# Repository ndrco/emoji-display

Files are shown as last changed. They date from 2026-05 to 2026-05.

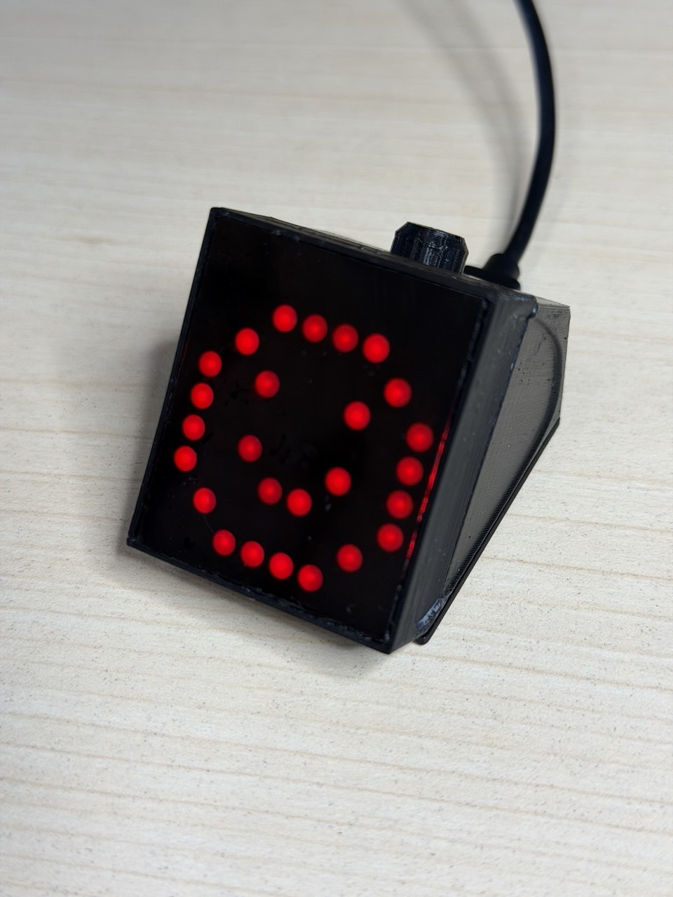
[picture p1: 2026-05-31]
Arduino/Case 3d model/photo_2026-05-31_19-20-57.jpg

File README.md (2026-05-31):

# emoji-display

`emoji-display` is a local bridge between applications and a small Arduino LED
emoji panel. It owns the serial port, normalizes incoming emoji to the limited
set supported by the 8x8 matrix, and exposes both HTTP and CLI interfaces.

The bundled firmware lives in
[`Arduino/max7219_emoji_panel`](Arduino/max7219_emoji_panel). Flash the Arduino
first, then come back here to install the daemon.

Files for the printable enclosure live in
[`Arduino/Case 3d model`](Arduino/Case%203d%20model).

## What You Get

- A local HTTP daemon for showing emoji on the panel.
- A `displayctl` CLI for testing and debugging.
- Automatic emoji normalization such as `😺 -> CAT`, `🚀 -> CAR`,
  `🌸 -> FLOWER`, `☔ -> RAIN`.
- Serial port auto-detection when the Arduino changes from `/dev/ttyACM0` to
  `/dev/ttyACM1`.
- `systemd` service templates for both system-wide and per-user installs.

## Quick Start

This is the shortest path from a freshly flashed Arduino to a working local
service on Linux.

1. Flash the firmware from
   [`Arduino/max7219_emoji_panel`](Arduino/max7219_emoji_panel).
2. Disconnect the Arduino IDE Serial Monitor after flashing.
3. Find the stable serial path:

```bash
ls -l /dev/serial/by-id/
```

You want the Arduino path, for example:

```text
/dev/serial/by-id/usb-Arduino_LLC_Arduino_Micro-if00
```

4. Clone the repository and install it:

```bash
git clone https://github.com/ndrco/emoji-display.git
cd emoji-display
python3 -m venv .venv
. .venv/bin/activate
pip install -e ".[dev]"
```

5. Start the daemon manually:

```bash
emoji-displayd --driver serial --serial-port /dev/serial/by-id/usb-Arduino_LLC_Arduino_Micro-if00
```

6. In another terminal, check that it is alive:

```bash
curl http://127.0.0.1:18791/v1/status
displayctl --url http://127.0.0.1:18791 status
```

When the driver opens the port it logs the resolved device, for example:

```text
opening serial display port /dev/serial/by-id/usb-Arduino_LLC_Arduino_Micro-if00 (configured)
```

If that works, continue to one of the service setups below.

## Requirements

- Linux, macOS, or Windows.
- Python 3.10+.
- A flashed Arduino-compatible board connected over USB.
- `pyserial` is installed automatically with the package.

Linux users should prefer `/dev/serial/by-id/...` over `/dev/ttyACM0` or
`/dev/ttyUSB0`, because the `by-id` path stays stable across reconnects.

## Run Manually

Explicit port:

```bash
emoji-displayd --driver serial --serial-port /dev/serial/by-id/usb-Arduino_LLC_Arduino_Micro-if00
```

Auto-detect:

```bash
emoji-displayd --driver serial
```

Auto-detect works well when one Arduino-like serial device is clearly
identifiable. When several USB serial devices are connected, the daemon tries
to prefer real Arduino metadata and then probes candidates for the panel boot
banner.

Windows PowerShell example:

```powershell
.\.venv\Scripts\emoji-displayd --driver serial --serial-port COM3
```

## Service Setup

There are two supported service styles:

- `systemd --user`: easiest when you install into your home directory and do
  not want `sudo`.
- system-wide `systemd`: best when the service should survive logout and live in
  `/opt/emoji-display`.

## User Service

This is the easiest GitHub-friendly Linux install.

1. Install the repo in your preferred location, for example
   `/home/<user>/Applications/emoji-display`.
2. Create an environment file:

```bash
mkdir -p ~/.config/emoji-display
cp packaging/systemd/emoji-display.env.example ~/.config/emoji-display/emoji-display.env
```

3. Edit `~/.config/emoji-display/emoji-display.env`.

Recommended:

```bash
EMOJI_DISPLAY_PORT=/dev/serial/by-id/usb-Arduino_LLC_Arduino_Micro-if00
```

Or leave `EMOJI_DISPLAY_PORT` unset to use auto-detection.

4. Create `~/.config/systemd/user/emoji-display.service`:

```ini
[Unit]
Description=Emoji Display Arduino bridge
Documentation=https://github.com/ndrco/emoji-display
After=default.target

[Service]
Type=simple
WorkingDirectory=/home/USER/Applications/emoji-display
EnvironmentFile=-/home/USER/.config/emoji-display/emoji-display.env
ExecStart=/home/USER/Applications/emoji-display/.venv/bin/emoji-displayd --driver serial
Restart=on-failure
RestartSec=3
NoNewPrivileges=true
PrivateTmp=true

[Install]
WantedBy=default.target
```

Replace `USER` with your real username.

5. Enable and start it:

```bash
systemctl --user daemon-reload
systemctl --user enable --now emoji-display.service
```

6. Verify:

```bash
systemctl --user status emoji-display.service
journalctl --user -u emoji-display.service -f
curl http://127.0.0.1:18791/v1/status
```

## System-Wide Service

Use this when you want a conventional machine-wide service.

```bash
sudo useradd --system --home-dir /opt/emoji-display \
  --shell /usr/sbin/nologin --groups dialout emoji-display
sudo mkdir -p /etc/emoji-display
sudo git clone https://github.com/ndrco/emoji-display.git /opt/emoji-display
sudo python3 -m venv /opt/emoji-display/.venv
sudo /opt/emoji-display/.venv/bin/pip install -e /opt/emoji-display
sudo cp packaging/systemd/emoji-display.env.example /etc/emoji-display/emoji-display.env
sudo nano /etc/emoji-display/emoji-display.env
sudo cp packaging/systemd/emoji-display.service /etc/systemd/system/emoji-display.service
sudo systemctl daemon-reload
sudo systemctl enable --now emoji-display
```

Then verify:

```bash
sudo systemctl status emoji-display
sudo journalctl -u emoji-display -f
curl http://127.0.0.1:18791/v1/status
```

Use a stable port in `/etc/emoji-display/emoji-display.env` when possible:

```bash
EMOJI_DISPLAY_PORT=/dev/serial/by-id/usb-Arduino_LLC_Arduino_Micro-if00
```

If you leave the port unset, watch the journal for the resolved port name.

## Verify The Install

Useful checks after any install:

```bash
curl http://127.0.0.1:18791/v1/status
displayctl --url http://127.0.0.1:18791 status
displayctl --url http://127.0.0.1:18791 supported
displayctl --url http://127.0.0.1:18791 show "😺"
displayctl --url http://127.0.0.1:18791 clear --reason test
```

Expected signs of success:

- `/v1/status` returns `"connected": true`.
- The reported `"port"` is the Arduino serial device.
- Logs contain `opening serial display port ...`.
- The matrix reacts to `displayctl show`.

## Troubleshooting

`The daemon says "multiple serial ports found"`:
Use `/dev/serial/by-id/...` explicitly, or disconnect the other USB serial
devices while testing.

`Nothing happens on the display`:
Make sure the Arduino IDE Serial Monitor is closed. Only one process can own the
serial port at a time.

`Permission denied on /dev/ttyACM0 or /dev/ttyUSB0`:
Your user probably needs the serial group, usually `dialout`. Some
distributions use `uucp` or `lock` instead.

`The Arduino changes from /dev/ttyACM0 to /dev/ttyACM1`:
Use `/dev/serial/by-id/...` in your env file instead of the moving `/dev/tty*`
name.

`The service started but the first HTTP request feels slow`:
The serial driver opens the Arduino lazily on first use and may wait for the
board reset timeout before the first response.

`Auto-detect still picks the wrong device`:
Pin `EMOJI_DISPLAY_PORT` to the exact `/dev/serial/by-id/...` path.

## Supported Display Names

The Arduino panel currently contains these display names:

```text
HAPPY LAUGH WINK SURPRISE SAD CRY ANGRY LOVE KISS COOL SLEEP NEUTRAL
CONFUSED THINK TONGUE DEAD WOW HEART YES NO OK ALERT MUSIC ROBOT GHOST
CAT DOG FOOD STAR CAR FLOWER RAIN DEFAULT
```

Emoji without an exact hardware drawing are classified by domain when possible:

- transport -> `CAR`
- plants -> `FLOWER`
- weather -> `RAIN`
- food and drinks -> `FOOD`
- music and instruments -> `MUSIC`
- sparkles, fireworks, stars -> `STAR`
- truly unknown -> `DEFAULT`

To add a new hardware icon, add frames to
[`Arduino/max7219_emoji_panel/emojis.h`](Arduino/max7219_emoji_panel/emojis.h)
and then add normalization rules in
[`src/emoji_display/emoji.py`](src/emoji_display/emoji.py).

## CLI

```bash
displayctl status
displayctl supported
displayctl normalize "😺"
displayctl show "😺"
displayctl clear --reason interrupt
```

Use top-level options before the command when the daemon is not running on
`http://127.0.0.1:18791`:

```bash
displayctl --url http://127.0.0.1:18791 status
```

If the daemon uses a bearer token, pass `--token`.

## HTTP API

`GET /v1/status`

```json
{
  "ok": true,
  "connected": true,
  "driver": "serial",
  "current": "😺",
  "display_name": "CAT",
  "display_symbol": "🐱",
  "queue_size": 0,
  "last_error": null
}
```

`GET /v1/supported`

`POST /v1/show`

```json
{
  "symbol": "😺",
  "name": "smiling_cat_face",
  "hold_ms": 7000,
  "mode": "replace",
  "source": "listener",
  "id": "run-123:segment-4:0"
}
```

If `hold_ms` is omitted, the server uses its default `7000` ms.

When a new symbol arrives while another one is still fresh, the daemon keeps
the current symbol for at most `1600` ms total, then replaces it with the latest
incoming symbol. The Arduino firmware has its own standalone default `1600` ms,
used only when the board receives `EMO <name>` without an explicit duration.

`POST /v1/sequence` is accepted for compatibility, but it never queues display
items. The daemon selects the last item in the request and ignores the rest.

`POST /v1/clear`

```json
{
  "source": "listener",
  "reason": "interrupt"
}
```

If `--token` is set, clients must send `Authorization: Bearer <token>`.

## Firmware And Hardware Notes

The wiring guide, component list, and firmware details live in
[`Arduino/max7219_emoji_panel/README.md`](Arduino/max7219_emoji_panel/README.md).
That document covers:

- required Arduino and MAX7219 hardware
- LDR and potentiometer wiring
- Arduino IDE setup
- the serial protocol
- manual hardware testing
- tuning brightness and animation timing

## Enclosure Files

Printable case assets live in
[`Arduino/Case 3d model`](Arduino/Case%203d%20model):

- `Top.stl`
- `Bottom.stl`
- `Display.stl`
- `Glass.stl`
- `Knob.stl`

The folder also includes:

- `Smileficator v18.png` as a render/preview
- `photo_2026-05-31_19-20-57.jpg` as a real build photo
- `video_2026-05-31_19-21-24.mp4` as a short demo clip

## Development

```bash
.venv/bin/python -m pytest -q
```

The Arduino helper
[`Arduino/max7219_emoji_panel/test_all_emojis.py`](Arduino/max7219_emoji_panel/test_all_emojis.py)
is a manual hardware test, not a pytest test:

```bash
python Arduino/max7219_emoji_panel/test_all_emojis.py /dev/ttyACM0
```

## Listener Config Example

```json
{
  "speaker": {
    "emoji_display": {
      "enabled": true,
      "url": "http://127.0.0.1:18791",
      "timeout_s": 0.25,
      "mode": "replace",
      "source": "listener",
      "send": "last",
      "clear_on_interrupt": true
    }
  }
}
```

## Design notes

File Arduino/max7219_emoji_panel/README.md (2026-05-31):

# MAX7219 8x8 Emoji Panel

Firmware for an Arduino-compatible board connected to one MAX7219 8x8 LED
matrix. The Python daemon sends normalized emoji names over Serial, and this
sketch renders the matching built-in animation.

After flashing the board, return to the repository root
[`README.md`](../../README.md) for daemon installation, service setup, and
verification steps.

If you want a printable enclosure for the hardware, see
[`../Case 3d model`](../Case%203d%20model).

## Components

- Arduino Pro Micro / Leonardo-compatible ATmega32U4 board, 5 V version.
- MAX7219 8x8 LED matrix module.
- LDR photoresistor, for example GL5528.
- 10 kOhm resistor for the LDR divider.
- 10 kOhm potentiometer for user brightness limit.
- Breadboard/jumper wires and a USB data cable.

Other Arduino boards can work too. If you use Uno, Nano, ESP32, or another
pinout, update `PIN_DIN`, `PIN_CLK`, and `PIN_CS` in `config.h`.

## Enclosure

3D-printable enclosure files are stored in
[`../Case 3d model`](../Case%203d%20model):

- `Top.stl`
- `Bottom.stl`
- `Display.stl`
- `Glass.stl`
- `Knob.stl`

That folder also contains one render image, one assembled-device photo, and one
short demo video for reference during printing and assembly.

## Wiring

The default pinout is for the current Pro Micro build:

A wiring snapshot is also available as
[`Schematic.png`](Schematic.png).

| Module | Arduino |
| --- | --- |
| MAX7219 VCC | 5V |
| MAX7219 GND | GND |
| MAX7219 DIN | D15 |
| MAX7219 CLK | D16 |
| MAX7219 CS | D10 |

LDR brightness sensor:

```text
5V --- LDR --- A0 --- 10 kOhm --- GND
```

Potentiometer:

```text
5V  --- outer pin
A1  --- middle pin
GND --- other outer pin
```

The LDR changes automatic brightness. The potentiometer limits the maximum
brightness so the display can be dimmed for a dark room.

## Arduino IDE Setup

1. Install the `LedControl` library from Library Manager.
2. Select a board matching your controller. For many Pro Micro clones, use
   `SparkFun Pro Micro` if SparkFun AVR boards are installed, or `Arduino
   Leonardo` for a compatible ATmega32U4 profile.
3. Open `max7219_emoji_panel.ino`.
4. Check pins and brightness calibration in `config.h`.
5. Upload the sketch.
6. Open Serial Monitor at `115200` baud with line ending `Newline`.

After power-up, the panel plays a short welcome splash once before it starts
accepting normal display commands. You can tune or disable this in `config.h`
with `STARTUP_SPLASH_ENABLED`, `STARTUP_SPLASH_FRAME_MS`, and
`STARTUP_SPLASH_HOLD_MS`.

## Serial Protocol

Commands are ASCII lines ending with `\n`:

```text
EMO <name> [ms] [fps]
IMG <b0> <b1> <b2> <b3> <b4> <b5> <b6> <b7> [ms]
LIST
CLEAR
DEBUG 1
DEBUG 0
HELP
```

Examples:

```text
EMO HAPPY 2000
EMO HEART 1600 15
EMO CAT 1600
CLEAR
LIST
IMG 0x3C 0x42 0xA5 0x81 0xA5 0x99 0x42 0x3C 1600
```

Responses used by the Python daemon:

```text
OK EMO CAT 1600
OK CLEAR
ERR: unknown EMO name. Try LIST.
```

`EMO` starts a non-blocking display state. While an animation is active, the
main loop still reads Serial, so a new `EMO` replaces the current one and
`CLEAR` clears the matrix immediately.

## Built-In Names

```text
HAPPY LAUGH WINK SURPRISE SAD CRY ANGRY LOVE KISS COOL SLEEP NEUTRAL
CONFUSED THINK TONGUE DEAD WOW HEART YES NO OK ALERT MUSIC ROBOT GHOST
CAT DOG FOOD STAR CAR FLOWER RAIN DEFAULT
```

Run `LIST` to get the same names with frame counts and FPS values.

## Manual Hardware Test

Close the Arduino IDE Serial Monitor before running the Python test helper.

```bash
python -m pip install pyserial
python Arduino/max7219_emoji_panel/test_all_emojis.py /dev/ttyACM0
```

On Windows:

```powershell
py -m pip install pyserial
py Arduino\max7219_emoji_panel\test_all_emojis.py COM3
```

The helper sends every name returned by `LIST`.

## Adding An Emoji

1. Add a PROGMEM name:

```cpp
const char NAME_MYEMO[] PROGMEM = "MYEMO";
```

2. Add frames. One frame is exactly 8 bytes, one byte per row:

```cpp
const uint8_t EMO_MYEMO[] PROGMEM = {
  // frame 0
  0b00111100, 0b01000010, 0b10100101, 0b10000001,
  0b10100101, 0b10011001, 0b01000010, 0b00111100,

  // frame 1
  0b00111100, 0b01000010, 0b10000001, 0b10000001,
  0b10100101, 0b10011001, 0b01000010, 0b00111100
};
```

3. Register it in `ANIMS`:

```cpp
{ NAME_MYEMO, EMO_MYEMO, 2, 7 },
```

The fields are `{ name, frame_array, frame_count, fps }`.
`frame_count` must be `1..MAX_ANIM_FRAMES`. `fps=0` uses
`DEFAULT_ANIM_FPS`.

4. Add Python normalization rules in
`src/emoji_display/emoji.py`, otherwise the daemon will not route user emoji to
the new display name.

## Tuning

Main settings are in `config.h`:

```cpp
const int LDR_DARK_ADC = 90;
const int LDR_BRIGHT_ADC = 760;
const uint8_t BRIGHTNESS_CURVE_PROFILE = 0;
const uint8_t MAX_ANIM_FRAMES = 4;
const uint8_t DEFAULT_ANIM_FPS = 8;
const uint8_t MIN_ANIM_FPS = 1;
const uint8_t MAX_ANIM_FPS = 30;
const uint16_t DEFAULT_SHOW_MS = 1600;
const int LDR_HYSTERESIS_ADC = 20;
```

If the LDR works backward because your divider is reversed, swap the LDR and
resistor positions or adjust `LDR_DARK_ADC` / `LDR_BRIGHT_ADC`.
If brightness still chatters near one light level, increase
`LDR_HYSTERESIS_ADC` a little, for example from `20` to `24` or `28`.

If the display becomes dim too quickly while room light falls, change
`BRIGHTNESS_CURVE_PROFILE`:

1. `0` = soft, keeps mid/low light levels brighter for longer.
2. `1` = balanced.
3. `2` = steep, darkens quickly.

If the LDR is mounted behind tinted glass or smoked acrylic, the ADC range
usually shifts downward a lot. In that case:

1. Send `DEBUG 1` in Serial Monitor.
2. Note `LDR raw=` in the darkest realistic condition.
3. Note `LDR raw=` in the brightest realistic condition.
4. Set `LDR_DARK_ADC` slightly below the dark reading.
5. Set `LDR_BRIGHT_ADC` slightly below or near the bright reading.

Example: if you see `raw=110` in the dark and `raw=720` in bright room light,
good starting values are `LDR_DARK_ADC = 90` and `LDR_BRIGHT_ADC = 760`.

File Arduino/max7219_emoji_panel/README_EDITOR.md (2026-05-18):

# emoji_editor.py

Графический редактор 8×8 анимаций для `emojis.h`.

## Запуск

```bash
cd max7219_emoji_panel
python3 emoji_editor.py
```

Если в системе нет Tkinter:

```bash
sudo apt install python3-tk
```

Можно явно указать файл и актуальную цифру Flash из Arduino IDE:

```bash
python3 emoji_editor.py --file ./emojis.h --flash-used 10466
```

## Что умеет

- открывать и сохранять `emojis.h`;
- редактировать 1–4 кадра для каждого эмодзи;
- задавать индивидуальный FPS;
- показывать Unicode emoji reference;
- подставлять имя по Unicode/CLDR-названию;
- приблизительно оценивать Flash;
- сохранять строки/столбцы во временном виртуальном буфере при сдвиге кадра;
- сбрасывать изменения текущего кадра кнопкой `Отменить`;
- сохранять текущий эмодзи кнопкой `Сохранить` с очисткой виртуального буфера;
- проигрывать анимацию текущего эмодзи кнопкой `Play`.

Оценка памяти приблизительная: редактор считает размер данных эмодзи во Flash (`имя + кадры + строка таблицы AnimDef`) и добавляет его к базовой оценке скетча из последней компиляции.

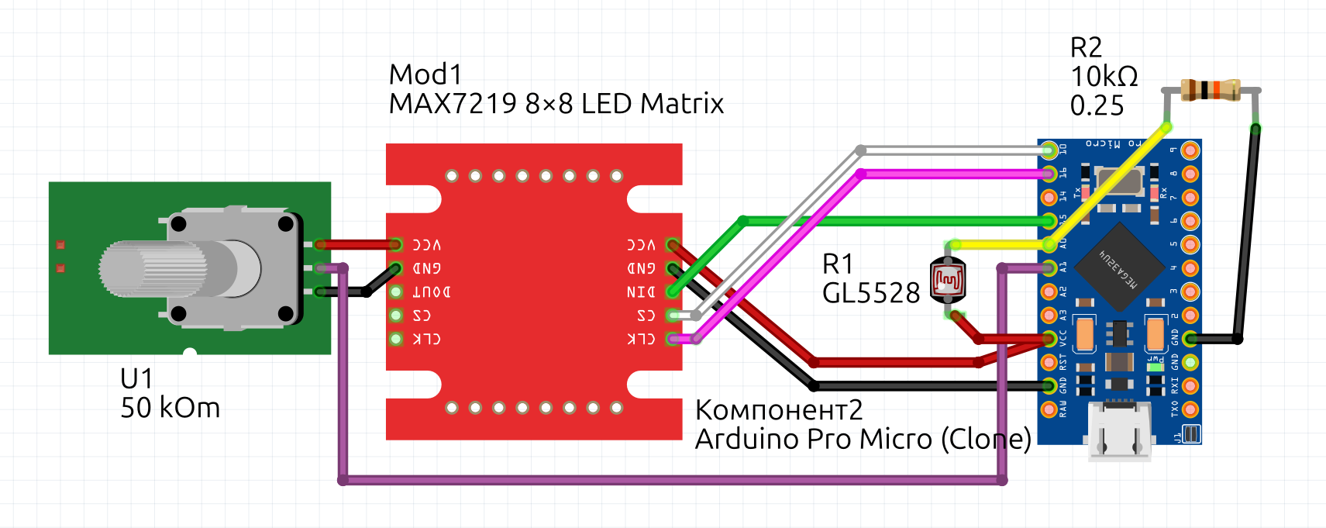
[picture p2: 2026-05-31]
Arduino/max7219_emoji_panel/Schematic.png

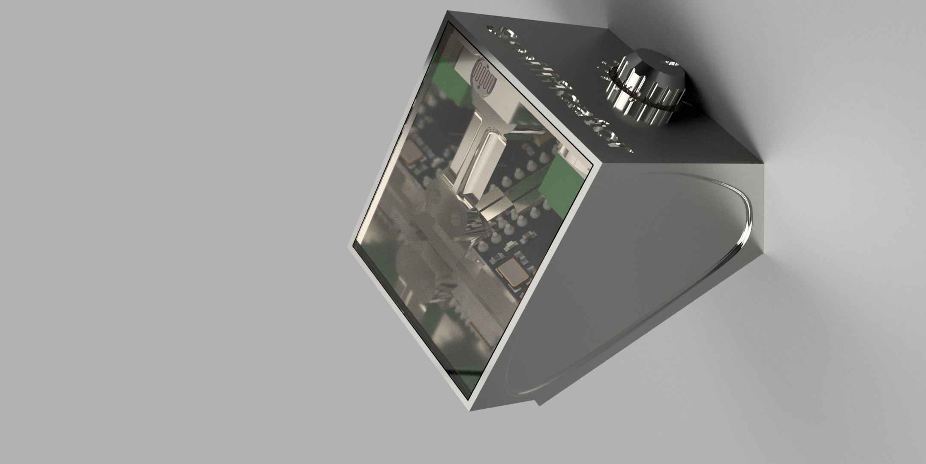
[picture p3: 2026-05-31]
Arduino/Case 3d model/Smileficator v18.png

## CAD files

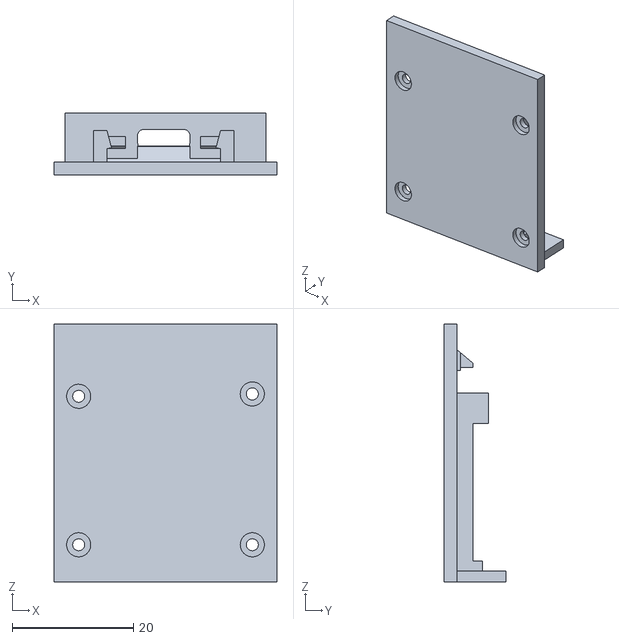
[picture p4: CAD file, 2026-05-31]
Arduino/Case 3d model/Bottom.stl
36.8 x 10.3 x 42.6

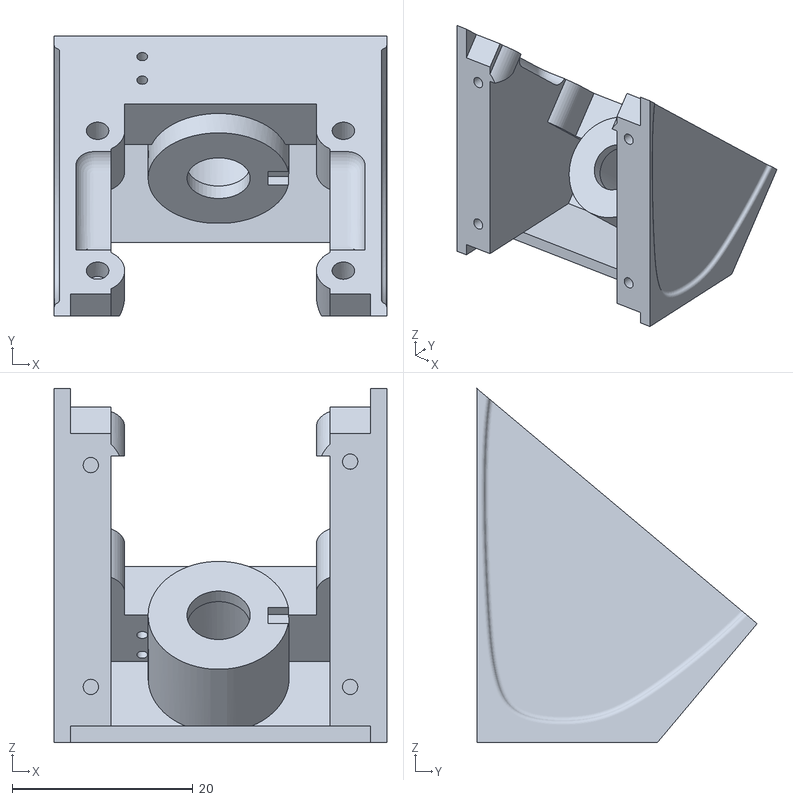
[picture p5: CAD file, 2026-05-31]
Arduino/Case 3d model/Top.stl
36.8 x 31.0 x 39.2

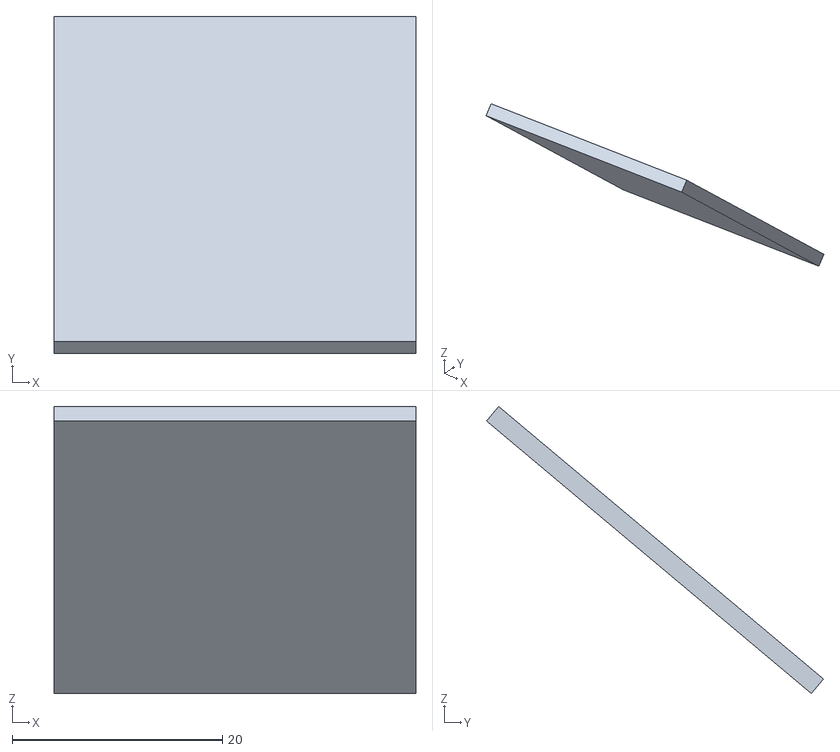
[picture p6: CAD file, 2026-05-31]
Arduino/Case 3d model/Glass.stl
34.4 x 32.0 x 27.3

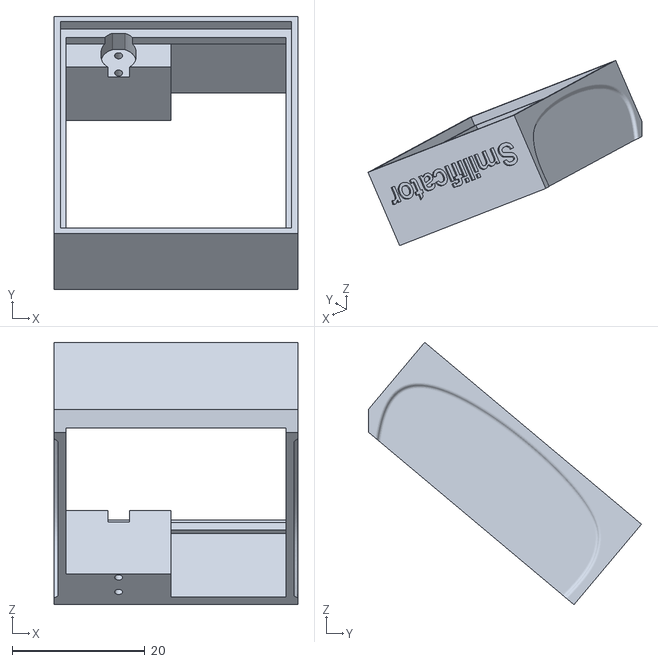
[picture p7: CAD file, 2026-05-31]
Arduino/Case 3d model/Display.stl
36.8 x 41.2 x 39.6

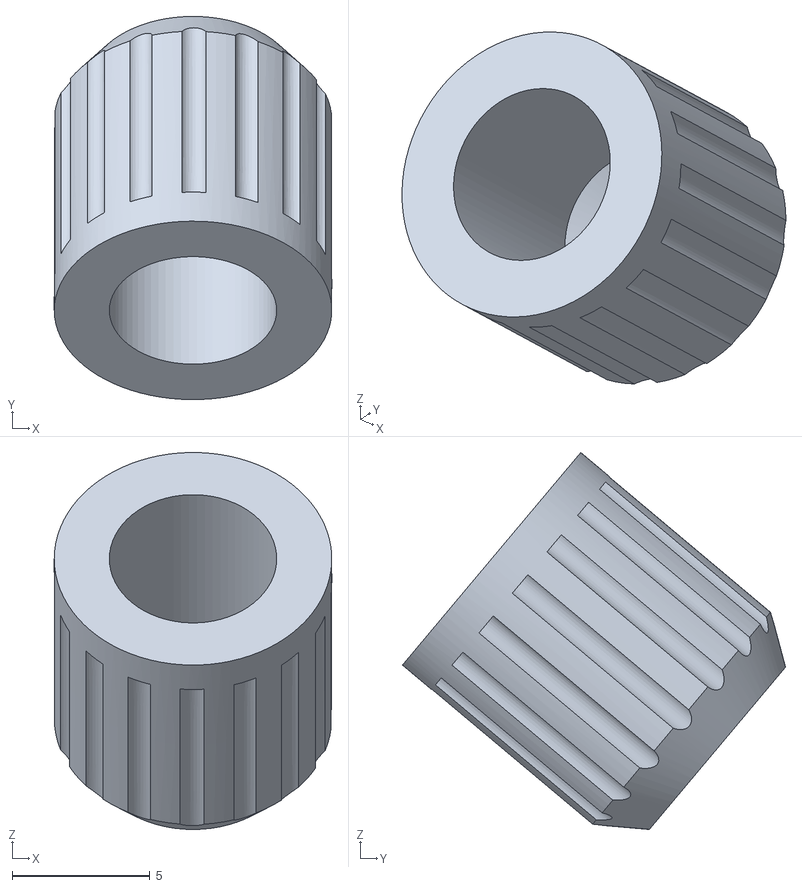
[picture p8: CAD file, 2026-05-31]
Arduino/Case 3d model/Knob.stl
10.1 x 13.9 x 13.7

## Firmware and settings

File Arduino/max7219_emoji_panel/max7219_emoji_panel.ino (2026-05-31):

/*
 * MAX7219 8x8 Emoji Panel
 * Board: Arduino Pro Micro / ATmega32U4 clone
 * Display: one MAX7219 8x8 LED matrix module
 *
 * Commands over Serial @115200:
 *   EMO <name> [ms] [fps]   Example: EMO HAPPY 1600
 *                            Example with temporary FPS override: EMO HEART 1600 15
 *   IMG <b0> ... <b7> [ms]  Example: IMG 0x3C 0x42 0xA5 0x81 0xA5 0x99 0x42 0x3C 1600
 *   LIST
 *   CLEAR
 *   DEBUG 1 / DEBUG 0
 *   HELP
 * Replies:
 *   OK ... on accepted commands, ERR: ... on invalid commands.
 *
 * Built-in emojis:
 *   Stored in PROGMEM.
 *   Each emoji can have 1..MAX_ANIM_FRAMES frames and its own FPS.
 *
 * Brightness:
 *   LDR divider on A0.
 *   Potentiometer on A1 limits maximum brightness.
 *   Gamma-like ADC -> intensity curve is implemented as a PROGMEM LUT, no pow()/math.h.
 */

#include <Arduino.h>
#include <LedControl.h>
#include <avr/pgmspace.h>
#include <stdlib.h>
#include "config.h"
#include "emojis.h"

LedControl lc(PIN_DIN, PIN_CLK, PIN_CS, MATRIX_COUNT);

// Brightness LUTs for LDR -> MAX7219 intensity mapping.
// Using PROGMEM LUTs keeps the behavior deterministic on AVR and makes
// curve tuning easier than runtime pow()/float math.
const uint8_t BRIGHTNESS_LUT_SOFT[64] PROGMEM = {
  0, 0, 0, 0, 0, 0, 1, 1,
  1, 1, 1, 1, 2, 2, 2, 2,
  2, 2, 3, 3, 3, 3, 4, 4,
  4, 4, 5, 5, 5, 6, 6, 6,
  7, 7, 7, 8, 8, 8, 9, 9,
  9,10,10,10,11,11,11,12,
 12,12,13,13,13,14,14,14,
 15,15,15,15,15,15,15,15
};

const uint8_t BRIGHTNESS_LUT_BALANCED[64] PROGMEM = {
  0, 0, 0, 0, 0, 0, 0, 0,
  0, 0, 0, 1, 1, 1, 1, 1,
  1, 1, 1, 2, 2, 2, 2, 2,
  2, 3, 3, 3, 3, 4, 4, 4,
  4, 5, 5, 5, 6, 6, 6, 7,
  7, 7, 8, 8, 9, 9, 9,10,
 10,10,11,11,12,12,13,13,
 13,14,14,15,15,15,15,15
};

const uint8_t BRIGHTNESS_LUT_STEEP[64] PROGMEM = {
  0, 0, 0, 0, 0, 0, 0, 0,
  0, 0, 0, 0, 0, 0, 0, 0,
  0, 0, 0, 1, 1, 1, 1, 1,
  1, 1, 1, 1, 2, 2, 2, 2,
  2, 2, 3, 3, 3, 3, 4, 4,
  4, 5, 5, 5, 5, 6, 6, 7,
  7, 7, 8, 8, 9, 9,10,10,
 11,11,12,12,13,14,14,15
};

char lineBuf[LINE_BUF_SIZE];
uint8_t linePos = 0;

int ldrEMA = LDR_EMA_INITIAL;
int lastRawLdr = 0;
int lastPot = 0;
uint8_t lastBaseIntensity = 0;
uint8_t lastIntensity = 0;
bool baseIntensityInitialized = false;
bool debugEnabled = false;
unsigned long lastDebugPrintMs = 0;

enum DisplayMode {
  DISPLAY_IDLE,
  DISPLAY_ANIM,
  DISPLAY_IMAGE
};

DisplayMode displayMode = DISPLAY_IDLE;
AnimDef activeAnim;
uint8_t activeFrame = 0;
uint8_t activeFrameCount = 1;
uint16_t activeFrameDelayMs = IMG_REFRESH_MS;
uint32_t activeUntilMs = 0;
uint32_t nextFrameMs = 0;
uint8_t activeImage[8];

const uint8_t SPLASH_HEART_SMALL[8] PROGMEM = {
  0b00000000, 0b00100100, 0b01111110, 0b11111111,
  0b11111111, 0b01111110, 0b00111100, 0b00011000
};

const uint8_t SPLASH_HEART_BIG[8] PROGMEM = {
  0b01100110, 0b11111111, 0b11111111, 0b11111111,
  0b01111110, 0b00111100, 0b00011000, 0b00000000
};

const uint8_t SPLASH_SMILE[8] PROGMEM = {
  0b00111100, 0b01000010, 0b10100101, 0b10000001,
  0b10100101, 0b10011001, 0b01000010, 0b00111100
};

// -------------------- Small helpers --------------------

bool isSpaceChar(char c)
{
  return c == ' ' || c == '\t';
}

char upperAscii(char c)
{
  if (c >= 'a' && c <= 'z') return c - 32;
  return c;
}

bool equalsIgnoreCase(const char *a, const char *b)
{
  while (*a && *b) {
    if (upperAscii(*a) != upperAscii(*b)) return false;
    a++;
    b++;
  }
  return *a == '\0' && *b == '\0';
}

bool equalsName_P(const char *ramName, PGM_P progmemName)
{
  while (true) {
    char a = upperAscii(*ramName++);
    char b = upperAscii((char)pgm_read_byte(progmemName++));

    if (a != b) return false;
    if (a == '\0') return true;
  }
}

long mapLong(long x, long inMin, long inMax, long outMin, long outMax)
{
  if (inMax == inMin) return outMin;
  return (x - inMin) * (outMax - outMin) / (inMax - inMin) + outMin;
}

const uint8_t *activeBrightnessLut()
{
  if (BRIGHTNESS_CURVE_PROFILE == 0) return BRIGHTNESS_LUT_SOFT;
  if (BRIGHTNESS_CURVE_PROFILE == 1) return BRIGHTNESS_LUT_BALANCED;
  return BRIGHTNESS_LUT_STEEP;
}

void printProgmemString(PGM_P p)
{
  char c;
  while ((c = (char)pgm_read_byte(p++)) != '\0') {
    Serial.write(c);
  }
}

bool parseULong(const char *s, unsigned long &out)
{
  if (s == nullptr || *s == '\0') return false;
  char *endPtr = nullptr;
  unsigned long v = strtoul(s, &endPtr, 0);
  if (endPtr == s || *endPtr != '\0') return false;
  out = v;
  return true;
}

bool parseLong(const char *s, long &out)
{
  if (s == nullptr || *s == '\0') return false;
  char *endPtr = nullptr;
  long v = strtol(s, &endPtr, 0);
  if (endPtr == s || *endPtr != '\0') return false;
  out = v;
  return true;
}

uint8_t clampFps(uint8_t fps)
{
  if (fps == 0) fps = DEFAULT_ANIM_FPS;
  if (fps < MIN_ANIM_FPS) fps = MIN_ANIM_FPS;
  if (fps > MAX_ANIM_FPS) fps = MAX_ANIM_FPS;
  return fps;
}

uint16_t frameDelayFromFps(uint8_t fps)
{
  fps = clampFps(fps);
  return (uint16_t)(1000UL / fps);
}

uint8_t safeFrameCount(uint8_t nFrames)
{
  if (nFrames < 1) return 1;
  if (nFrames > MAX_ANIM_FRAMES) return MAX_ANIM_FRAMES;
  return nFrames;
}

// Splits the current line buffer in place.
uint8_t splitTokens(char *line, char **argv, uint8_t maxTokens)
{
  uint8_t argc = 0;
  char *p = line;

  while (*p != '\0' && argc < maxTokens) {
    while (isSpaceChar(*p)) p++;
    if (*p == '\0') break;

    argv[argc++] = p;

    while (*p != '\0' && !isSpaceChar(*p)) p++;
    if (*p == '\0') break;

    *p = '\0';
    p++;
  }

  return argc;
}

bool readSerialLine()
{
  while (Serial.available() > 0) {
    char c = (char)Serial.read();

    if (c == '\r') continue;

    if (c == '\n') {
      lineBuf[linePos] = '\0';
      linePos = 0;
      return lineBuf[0] != '\0';
    }

    if (linePos < LINE_BUF_SIZE - 1) {
      lineBuf[linePos++] = c;
    } else {
      // Line is too long. Keep the buffer safely terminated.
      lineBuf[LINE_BUF_SIZE - 1] = '\0';
    }
  }

  return false;
}

// -------------------- Brightness --------------------

uint8_t baseIntensityFromAdc(int adc)
{
  const uint8_t *lut = activeBrightnessLut();

  if (adc < LDR_DARK_ADC) adc = LDR_DARK_ADC;
  if (adc > LDR_BRIGHT_ADC) adc = LDR_BRIGHT_ADC;

  int idx = (int)mapLong(adc, LDR_DARK_ADC, LDR_BRIGHT_ADC, 0, 63);
  if (idx < 0) idx = 0;
  if (idx > 63) idx = 63;

  return pgm_read_byte(lut + idx);
}

int adcForLutIndex(int idx)
{
  if (idx < 0) idx = 0;
  if (idx > 63) idx = 63;
  return (int)mapLong(idx, 0, 63, LDR_DARK_ADC, LDR_BRIGHT_ADC);
}

int lowerAdcForIntensity(uint8_t intensity)
{
  const uint8_t *lut = activeBrightnessLut();

  for (int idx = 0; idx < 64; idx++) {
    uint8_t level = pgm_read_byte(lut + idx);
    if (level >= intensity) {
      return adcForLutIndex(idx);
    }
  }

  return LDR_BRIGHT_ADC;
}

int upperAdcForIntensity(uint8_t intensity)
{
  const uint8_t *lut = activeBrightnessLut();

  for (int idx = 63; idx >= 0; idx--) {
    uint8_t level = pgm_read_byte(lut + idx);
    if (level <= intensity) {
      return adcForLutIndex(idx);
    }
  }

  return LDR_DARK_ADC;
}

uint8_t baseIntensityWithHysteresis(int adc, uint8_t targetIntensity)
{
  if (!baseIntensityInitialized) {
    baseIntensityInitialized = true;
    return targetIntensity;
  }

  uint8_t current = lastBaseIntensity;
  if (targetIntensity == current) return current;

  if (targetIntensity > current && current < MAX_INTENSITY) {
    int riseAdc = lowerAdcForIntensity(current + 1) + LDR_HYSTERESIS_ADC;
    if (adc < riseAdc) return current;
  } else if (targetIntensity < current && current > MIN_INTENSITY) {
    int fallAdc = upperAdcForIntensity(current - 1) - LDR_HYSTERESIS_ADC;
    if (adc > fallAdc) return current;
  }

  return targetIntensity;
}

uint8_t applyPotLimit(uint8_t baseIntensity)
{
  lastPot = analogRead(POT_PIN);

  int userMax = (int)mapLong(lastPot, 0, 1023, USER_MAX_INTENSITY_MIN, USER_MAX_INTENSITY_MAX);
  if (userMax < USER_MAX_INTENSITY_MIN) userMax = USER_MAX_INTENSITY_MIN;
  if (userMax > USER_MAX_INTENSITY_MAX) userMax = USER_MAX_INTENSITY_MAX;

  int limited = (int)mapLong(baseIntensity, 0, 15, 0, userMax);
  if (limited < MIN_INTENSITY) limited = MIN_INTENSITY;
  if (limited > MAX_INTENSITY) limited = MAX_INTENSITY;

  return (uint8_t)limited;
}

uint8_t readAutoIntensity()
{
  lastRawLdr = analogRead(LDR_PIN);

  // Integer exponential moving average. No float math on small AVR boards.
  ldrEMA = ((long)ldrEMA * (LDR_EMA_DIV - 1) + lastRawLdr) / LDR_EMA_DIV;

  uint8_t targetBaseIntensity = baseIntensityFromAdc(ldrEMA);
  lastBaseIntensity = baseIntensityWithHysteresis(ldrEMA, targetBaseIntensity);
  lastIntensity = applyPotLimit(lastBaseIntensity);
  return lastIntensity;
}

void applyAutoBrightness()
{
  lc.setIntensity(0, readAutoIntensity());
}

void maybePrintDebug()
{
  if (!debugEnabled) return;

  unsigned long now = millis();
  if (now - lastDebugPrintMs < DEBUG_PRINT_PERIOD_MS) return;
  lastDebugPrintMs = now;

  Serial.print(F("LDR raw="));
  Serial.print(lastRawLdr);
  Serial.print(F(" ema="));
  Serial.print(ldrEMA);
  Serial.print(F(" base="));
  Serial.print(lastBaseIntensity);
  Serial.print(F(" pot="));
  Serial.print(lastPot);
  Serial.print(F(" intensity="));
  Serial.println(lastIntensity);
}

// -------------------- Display --------------------

void drawBitmapRam(const uint8_t *bmp)
{
  for (uint8_t row = 0; row < 8; row++) {
    lc.setRow(0, row, bmp[row]);
  }
}

void drawFrame_P(const uint8_t *frames, uint8_t frameIndex)
{
  const uint8_t *frame = frames + ((uint16_t)frameIndex * 8);

  for (uint8_t row = 0; row < 8; row++) {
    uint8_t v = pgm_read_byte(frame + row);
    lc.setRow(0, row, v);
  }
}

void fadeOutFrom(uint8_t startIntensity)
{
  for (int i = startIntensity; i >= 0; i--) {
    lc.setIntensity(0, i);
    delay(FADE_STEP_DELAY_MS);
  }
  lc.clearDisplay(0);
}

void playStartupSplash()
{
  if (!STARTUP_SPLASH_ENABLED) return;

  const uint8_t *const frames[] = {
    SPLASH_HEART_SMALL,
    SPLASH_HEART_BIG,
    SPLASH_SMILE
  };

  for (uint8_t i = 0; i < 3; i++) {
    drawFrame_P(frames[i], 0);
    applyAutoBrightness();
    delay(STARTUP_SPLASH_FRAME_MS);
  }

  delay(STARTUP_SPLASH_HOLD_MS);
  fadeOutFrom(readAutoIntensity());
}

// -------------------- Emoji registry --------------------

int findAnimIndexByName(const char *name)
{
  for (uint8_t i = 0; i < N_ANIMS; i++) {
    AnimDef a;
    memcpy_P(&a, &ANIMS[i], sizeof(a));

    if (equalsName_P(name, a.name)) {
      return i;
    }
  }

  return -1;
}

void printList()
{
  Serial.println(F("Available EMO names:"));

  for (uint8_t i = 0; i < N_ANIMS; i++) {
    AnimDef a;
    memcpy_P(&a, &ANIMS[i], sizeof(a));

    uint8_t frames = safeFrameCount(a.nFrames);
    uint8_t fps = clampFps(a.fps);

    Serial.print(F("  "));
    printProgmemString(a.name);
    Serial.print(F(" frames="));
    Serial.print(frames);
    Serial.print(F(" fps="));
    Serial.println(fps);
  }
}

bool timeReached(uint32_t now, uint32_t target)
{
  return (int32_t)(now - target) >= 0;
}

void stopDisplay(bool clearPanel)
{
  displayMode = DISPLAY_IDLE;
  activeFrame = 0;
  if (clearPanel) {
    lc.clearDisplay(0);
  }
}

void drawActiveFrame()
{
  if (displayMode == DISPLAY_ANIM) {
    drawFrame_P(activeAnim.frames, activeFrame);
    activeFrame++;
    if (activeFrame >= activeFrameCount) activeFrame = 0;
  } else if (displayMode == DISPLAY_IMAGE) {
    drawBitmapRam(activeImage);
  }

  applyAutoBrightness();
  nextFrameMs = millis() + activeFrameDelayMs;
}

void updateDisplay()
{
  if (displayMode == DISPLAY_IDLE) {
    applyAutoBrightness();
    return;
  }

  uint32_t now = millis();
  if (timeReached(now, activeUntilMs)) {
    fadeOutFrom(readAutoIntensity());
    stopDisplay(false);
    return;
  }

  if (timeReached(now, nextFrameMs)) {
    drawActiveFrame();
  } else {
    applyAutoBrightness();
  }
}

void startAnimByIndex(int index, uint32_t showMs, uint8_t fpsOverride)
{
  if (index < 0 || index >= N_ANIMS) return;

  memcpy_P(&activeAnim, &ANIMS[index], sizeof(activeAnim));
  activeFrameCount = safeFrameCount(activeAnim.nFrames);
  uint8_t fps = (fpsOverride == 0) ? activeAnim.fps : fpsOverride;
  activeFrameDelayMs = frameDelayFromFps(fps);
  activeFrame = 0;
  activeUntilMs = millis() + showMs;
  nextFrameMs = 0;
  displayMode = DISPLAY_ANIM;
  drawActiveFrame();
}

void startImage(const uint8_t bmp[8], uint32_t showMs)
{
  for (uint8_t i = 0; i < 8; i++) {
    activeImage[i] = bmp[i];
  }

  activeFrameDelayMs = IMG_REFRESH_MS;
  activeFrame = 0;
  activeFrameCount = 1;
  activeUntilMs = millis() + showMs;
  nextFrameMs = 0;
  displayMode = DISPLAY_IMAGE;
  drawActiveFrame();
}

// -------------------- Commands --------------------

void printHelp()
{
  Serial.println(F("Commands:"));
  Serial.println(F("  EMO <name> [ms] [fps]"));
  Serial.println(F("  IMG <b0> <b1> <b2> <b3> <b4> <b5> <b6> <b7> [ms]"));
  Serial.println(F("  LIST"));
  Serial.println(F("  CLEAR"));
  Serial.println(F("  DEBUG 1"));
  Serial.println(F("Examples:"));
  Serial.println(F("  EMO HAPPY 1600"));
  Serial.println(F("  EMO HEART 1600 15"));
  Serial.println(F("  IMG 0x3C 0x42 0xA5 0x81 0xA5 0x99 0x42 0x3C 1600"));
}

void handleEmoCommand(char **argv, uint8_t argc)
{
  if (argc < 2) {
    Serial.println(F("ERR: EMO needs name. Try LIST."));
    return;
  }

  uint32_t showMs = DEFAULT_SHOW_MS;
  if (argc >= 3) {
    unsigned long parsed = 0;
    if (!parseULong(argv[2], parsed)) {
      Serial.println(F("ERR: bad duration."));
      return;
    }
    showMs = parsed;
  }

  uint8_t fpsOverride = 0;
  if (argc >= 4) {
    unsigned long parsed = 0;
    if (!parseULong(argv[3], parsed)) {
      Serial.println(F("ERR: bad FPS."));
      return;
    }
    if (parsed > 255) parsed = 255;
    fpsOverride = (uint8_t)parsed;
  }

  int index = findAnimIndexByName(argv[1]);
  if (index < 0) {
    Serial.println(F("ERR: unknown EMO name. Try LIST."));
    return;
  }

  Serial.print(F("OK EMO "));
  Serial.print(argv[1]);
  Serial.print(F(" "));
  Serial.println(showMs);
  startAnimByIndex(index, showMs, fpsOverride);
}

void handleImgCommand(char **argv, uint8_t argc)
{
  if (argc < 9) {
    Serial.println(F("ERR: IMG needs 8 row bytes."));
    return;
  }

  uint8_t rows[8];

  for (uint8_t i = 0; i < 8; i++) {
    long v = 0;
    if (!parseLong(argv[i + 1], v)) {
      Serial.println(F("ERR: bad IMG byte."));
      return;
    }
    if (v < 0) v = 0;
    if (v > 255) v = 255;
    rows[i] = (uint8_t)v;
  }

  uint32_t showMs = DEFAULT_SHOW_MS;
  if (argc >= 10) {
    unsigned long parsed = 0;
    if (!parseULong(argv[9], parsed)) {
      Serial.println(F("ERR: bad duration."));
      return;
    }
    showMs = parsed;
  }

  Serial.println(F("OK IMG"));
  startImage(rows, showMs);
}

void handleDebugCommand(char **argv, uint8_t argc)
{
  if (argc < 2) {
    Serial.println(debugEnabled ? F("DEBUG=1") : F("DEBUG=0"));
    return;
  }

  unsigned long v = 0;
  if (!parseULong(argv[1], v)) {
    Serial.println(F("ERR: DEBUG needs 0 or 1."));
    return;
  }

  debugEnabled = (v != 0);
  Serial.println(debugEnabled ? F("DEBUG=1") : F("DEBUG=0"));
}

void handleCommand(char *line)
{
  char *argv[MAX_TOKENS];
  uint8_t argc = splitTokens(line, argv, MAX_TOKENS);
  if (argc == 0) return;

  if (equalsIgnoreCase(argv[0], "EMO")) {
    handleEmoCommand(argv, argc);
  } else if (equalsIgnoreCase(argv[0], "IMG")) {
    handleImgCommand(argv, argc);
  } else if (equalsIgnoreCase(argv[0], "LIST")) {
    printList();
  } else if (equalsIgnoreCase(argv[0], "CLEAR")) {
    stopDisplay(true);
    Serial.println(F("OK CLEAR"));
  } else if (equalsIgnoreCase(argv[0], "DEBUG")) {
    handleDebugCommand(argv, argc);
  } else if (equalsIgnoreCase(argv[0], "HELP") || equalsIgnoreCase(argv[0], "?")) {
    printHelp();
  } else {
    Serial.println(F("ERR: unknown command. Try HELP."));
  }
}

// -------------------- Arduino lifecycle --------------------

void setup()
{
  Serial.begin(SERIAL_BAUD);
  pinMode(LDR_PIN, INPUT);
  pinMode(POT_PIN, INPUT);

  lc.shutdown(0, false);
  lc.setIntensity(0, 8);
  lc.clearDisplay(0);
  playStartupSplash();

  Serial.println(F("MAX7219 8x8 Emoji Panel ready."));
  printHelp();
  printList();
}

void loop()
{
  if (readSerialLine()) {
    handleCommand(lineBuf);
  }

  updateDisplay();
  maybePrintDebug();
  delay(2);
}

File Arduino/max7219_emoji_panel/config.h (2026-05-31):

#pragma once

#include <Arduino.h>

// MAX7219 pins.
// Current working Pro Micro wiring:
//   DIN -> D15
//   CLK -> D16
//   CS  -> D10
// LedControl uses bit-banged output, so these do not have to be hardware SPI pins.
#define PIN_DIN 15
#define PIN_CLK 16
#define PIN_CS  10
#define MATRIX_COUNT 1

// Analog inputs
#define LDR_PIN A0
#define POT_PIN A1

// Measured values for the current LDR divider behind tinted glass:
// bright room/daylight: about 650..780, normal room: 300..550, dark: 80..180
// If the panel still reacts too weakly, lower LDR_BRIGHT_ADC a bit more.
const int LDR_DARK_ADC   = 10;
const int LDR_BRIGHT_ADC = 700;

// MAX7219 intensity range. 0 is minimum brightness, not complete shutdown.
const uint8_t MIN_INTENSITY = 0;
const uint8_t MAX_INTENSITY = 15;

// Brightness curve profile for LDR -> MAX7219 intensity mapping.
// 0 = soft, keeps the display brighter longer while ambient light falls
// 1 = balanced
// 2 = steep, darkens faster
const uint8_t BRIGHTNESS_CURVE_PROFILE = 1;

// Potentiometer limits the maximum display brightness to this range.
const uint8_t USER_MAX_INTENSITY_MIN = 3;
const uint8_t USER_MAX_INTENSITY_MAX = 15;

// Integer EMA smoothing for LDR readings: 8 ~= alpha 0.125.
const uint8_t LDR_EMA_DIV = 8;
const int LDR_EMA_INITIAL = 500;

// Extra ADC margin before switching to a neighboring brightness level.
// This hysteresis reduces visible flicker near threshold values.
const int LDR_HYSTERESIS_ADC = 20;

// Animation timing.
// Each built-in emoji has its own FPS in emojis.h. If an emoji entry has fps=0,
// DEFAULT_ANIM_FPS is used.
const uint8_t MAX_ANIM_FRAMES = 4;
const uint8_t DEFAULT_ANIM_FPS = 8;
const uint8_t MIN_ANIM_FPS = 1;
const uint8_t MAX_ANIM_FPS = 30;
const uint16_t DEFAULT_SHOW_MS = 1600;
const uint16_t IMG_REFRESH_MS = 120;
const uint16_t FADE_STEP_DELAY_MS = 35;
const bool STARTUP_SPLASH_ENABLED = true;
const uint16_t STARTUP_SPLASH_FRAME_MS = 220;
const uint16_t STARTUP_SPLASH_HOLD_MS = 450;

// Serial
const uint32_t SERIAL_BAUD = 115200;
const uint8_t LINE_BUF_SIZE = 128;
const uint8_t MAX_TOKENS = 16;

// Optional diagnostics. Can be toggled with: DEBUG 1 / DEBUG 0
const uint16_t DEBUG_PRINT_PERIOD_MS = 500;

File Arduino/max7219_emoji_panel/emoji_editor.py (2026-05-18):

#!/usr/bin/env python3
"""
MAX7219 Emoji Editor
====================

Простой Tkinter-редактор 8x8 эмодзи/анимаций для проекта max7219_emoji_panel.
Умеет:
  - читать текущий emojis.h;
  - редактировать до 4 кадров на эмодзи;
  - задавать индивидуальный FPS;
  - показывать Unicode emoji reference и предлагать имя по Unicode/CLDR-названию;
  - сохранять обновлённый emojis.h в формате, который использует прошивка;
  - примерно оценивать Flash относительно последней компиляции.

Запуск:
  python3 emoji_editor.py
  python3 emoji_editor.py --file ./emojis.h

Зависимости: только стандартная библиотека Python 3 + tkinter.
На Ubuntu, если tkinter не установлен:
  sudo apt install python3-tk
"""
from __future__ import annotations

import argparse
import copy
import os
import re
import sys
import unicodedata
from dataclasses import dataclass, field
from pathlib import Path
from typing import Dict, List, Optional, Set, Tuple

try:
    import tkinter as tk
    from tkinter import filedialog, messagebox, simpledialog, ttk
except Exception as exc:  # pragma: no cover - GUI dependency
    print("Не удалось импортировать tkinter.")
    print("На Ubuntu установи: sudo apt install python3-tk")
    print(f"Ошибка: {exc}")
    raise

# -----------------------------------------------------------------------------
# Параметры железа/прошивки. Их можно переопределить из CLI.
# -----------------------------------------------------------------------------
DEFAULT_TOTAL_FLASH = 28672
DEFAULT_COMPILED_FLASH_USED = 10466

MAX_ANIM_FRAMES = 4
MIN_FPS = 1
MAX_FPS = 30
DEFAULT_FPS = 8

CELL = 34
GRID_PAD = 10

# -----------------------------------------------------------------------------
# Unicode reference.
# Если установлен пакет emoji, редактор сможет взять большой список из него.
# Без него используется встроенный набор самых ходовых emoji.
# -----------------------------------------------------------------------------
FALLBACK_UNICODE_EMOJIS: List[Tuple[str, str]] = [
    ("😀", "GRINNING FACE"),
    ("😃", "GRINNING FACE WITH BIG EYES"),
    ("😄", "GRINNING FACE WITH SMILING EYES"),
    ("😁", "BEAMING FACE WITH SMILING EYES"),
    ("😆", "GRINNING SQUINTING FACE"),
    ("😅", "GRINNING FACE WITH SWEAT"),
    ("😂", "FACE WITH TEARS OF JOY"),
    ("🤣", "ROLLING ON THE FLOOR LAUGHING"),
    ("🙂", "SLIGHTLY SMILING FACE"),
    ("🙃", "UPSIDE-DOWN FACE"),
    ("😉", "WINKING FACE"),
    ("😊", "SMILING FACE WITH SMILING EYES"),
    ("😇", "SMILING FACE WITH HALO"),
    ("🥰", "SMILING FACE WITH HEARTS"),
    ("😍", "SMILING FACE WITH HEART-EYES"),
    ("😘", "FACE BLOWING A KISS"),
    ("😗", "KISSING FACE"),
    ("😋", "FACE SAVORING FOOD"),
    ("😛", "FACE WITH TONGUE"),
    ("😜", "WINKING FACE WITH TONGUE"),
    ("🤪", "ZANY FACE"),
    ("😎", "SMILING FACE WITH SUNGLASSES"),
    ("🤓", "NERD FACE"),
    ("🧐", "FACE WITH MONOCLE"),
    ("🤔", "THINKING FACE"),
    ("🤨", "FACE WITH RAISED EYEBROW"),
    ("😐", "NEUTRAL FACE"),
    ("😑", "EXPRESSIONLESS FACE"),
    ("😶", "FACE WITHOUT MOUTH"),
    ("😏", "SMIRKING FACE"),
    ("😒", "UNAMUSED FACE"),
    ("🙄", "FACE WITH ROLLING EYES"),
    ("😬", "GRIMACING FACE"),
    ("😮", "FACE WITH OPEN MOUTH"),
    ("😯", "HUSHED FACE"),
    ("😲", "ASTONISHED FACE"),
    ("😳", "FLUSHED FACE"),
    ("🥺", "PLEADING FACE"),
    ("😦", "FROWNING FACE WITH OPEN MOUTH"),
    ("😧", "ANGUISHED FACE"),
    ("😨", "FEARFUL FACE"),
    ("😰", "ANXIOUS FACE WITH SWEAT"),
    ("😥", "SAD BUT RELIEVED FACE"),
    ("😢", "CRYING FACE"),
    ("😭", "LOUDLY CRYING FACE"),
    ("😱", "FACE SCREAMING IN FEAR"),
    ("😖", "CONFOUNDED FACE"),
    ("😣", "PERSEVERING FACE"),
    ("😞", "DISAPPOINTED FACE"),
    ("😓", "DOWNCAST FACE WITH SWEAT"),
    ("😩", "WEARY FACE"),
    ("😫", "TIRED FACE"),
    ("🥱", "YAWNING FACE"),
    ("😤", "FACE WITH STEAM FROM NOSE"),
    ("😡", "POUTING FACE"),
    ("😠", "ANGRY FACE"),
    ("🤬", "FACE WITH SYMBOLS ON MOUTH"),
    ("😴", "SLEEPING FACE"),
    ("🤯", "EXPLODING HEAD"),
    ("🥳", "PARTYING FACE"),
    ("🥶", "COLD FACE"),
    ("🥵", "HOT FACE"),
    ("🤖", "ROBOT"),
    ("👻", "GHOST"),
    ("💀", "SKULL"),
    ("👽", "ALIEN"),
    ("😺", "GRINNING CAT"),
    ("😸", "GRINNING CAT WITH SMILING EYES"),
    ("😹", "CAT WITH TEARS OF JOY"),
    ("😻", "SMILING CAT WITH HEART-EYES"),
    ("😼", "CAT WITH WRY SMILE"),
    ("🙀", "WEARY CAT"),
    ("🐶", "DOG FACE"),
    ("🐱", "CAT FACE"),
    ("🐭", "MOUSE FACE"),
    ("🐹", "HAMSTER"),
    ("🐰", "RABBIT FACE"),
    ("🐻", "BEAR"),
    ("🐼", "PANDA"),
    ("🐸", "FROG"),
    ("🐵", "MONKEY FACE"),
    ("❤️", "RED HEART"),
    ("🧡", "ORANGE HEART"),
    ("💛", "YELLOW HEART"),
    ("💚", "GREEN HEART"),
    ("💙", "BLUE HEART"),
    ("💜", "PURPLE HEART"),
    ("🤍", "WHITE HEART"),
    ("🖤", "BLACK HEART"),
    ("💔", "BROKEN HEART"),
    ("💕", "TWO HEARTS"),
    ("💖", "SPARKLING HEART"),
    ("💘", "HEART WITH ARROW"),
    ("⭐", "STAR"),
    ("🌟", "GLOWING STAR"),
    ("✨", "SPARKLES"),
    ("💫", "DIZZY"),
    ("🎆", "FIREWORKS"),
    ("🎇", "SPARKLER"),
    ("🔥", "FIRE"),
    ("💥", "COLLISION"),
    ("⚡", "HIGH VOLTAGE"),
    ("💧", "DROPLET"),
    ("☀️", "SUN"),
    ("🌙", "CRESCENT MOON"),
    ("☁️", "CLOUD"),
    ("🌧️", "CLOUD WITH RAIN"),
    ("⛈️", "CLOUD WITH LIGHTNING AND RAIN"),
    ("☔", "UMBRELLA WITH RAIN DROPS"),
    ("❄️", "SNOWFLAKE"),
    ("✅", "CHECK MARK BUTTON"),
    ("❌", "CROSS MARK"),
    ("⭕", "HOLLOW RED CIRCLE"),
    ("⚠️", "WARNING"),
    ("❗", "RED EXCLAMATION MARK"),
    ("❓", "RED QUESTION MARK"),
    ("👍", "THUMBS UP"),
    ("👎", "THUMBS DOWN"),
    ("👌", "OK HAND"),
    ("👏", "CLAPPING HANDS"),
    ("🙏", "FOLDED HANDS"),
    ("👋", "WAVING HAND"),
    ("🎵", "MUSICAL NOTE"),
    ("🎶", "MUSICAL NOTES"),
    ("🎸", "GUITAR"),
    ("🎹", "MUSICAL KEYBOARD"),
    ("🥁", "DRUM"),
    ("☕", "HOT BEVERAGE"),
    ("🍕", "PIZZA"),
    ("🍔", "HAMBURGER"),
    ("🚗", "AUTOMOBILE"),
    ("🚀", "ROCKET"),
    ("✈️", "AIRPLANE"),
    ("🛸", "FLYING SAUCER"),
    ("🌸", "CHERRY BLOSSOM"),
    ("🌹", "ROSE"),
    ("🌱", "SEEDLING"),
    ("🌳", "DECIDUOUS TREE"),
    ("🔔", "BELL"),
    ("🔕", "BELL WITH SLASH"),
    ("⏰", "ALARM CLOCK"),
    ("💡", "LIGHT BULB"),
    ("🔋", "BATTERY"),
    ("🔌", "ELECTRIC PLUG"),
]
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

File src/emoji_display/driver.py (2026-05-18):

from __future__ import annotations

import logging
import os
import time
from dataclasses import dataclass
from typing import Any, Callable, Protocol

from .emoji import normalize_emoji

log = logging.getLogger(__name__)

_AUTO_DETECT_BANNER_MARKERS = (
    "MAX7219 8x8 Emoji Panel ready.",
    "Available EMO names:",
    "Commands:",
)
_ARDUINO_USB_IDS = {
    (0x2341, 0x8037),  # Arduino Micro
    (0x2341, 0x8036),  # Leonardo
    (0x2341, 0x0037),  # older Arduino Micro VID/PID pair
    (0x2341, 0x0036),  # older Leonardo VID/PID pair
    (0x2A03, 0x8037),  # Arduino.org Micro
    (0x2A03, 0x8036),  # Arduino.org Leonardo
    (0x1B4F, 0x9205),  # SparkFun Pro Micro 5V
    (0x1B4F, 0x9203),  # SparkFun Pro Micro 3.3V
}


@dataclass(frozen=True, slots=True)
class DisplayItem:
    symbol: str
    name: str | None = None
    hold_ms: int = 1200
    display_name: str | None = None
    display_symbol: str | None = None


class DisplayDriver(Protocol):
    name: str

    def show(self, item: DisplayItem) -> None:
        ...

    def clear(self) -> None:
        ...

    def status(self) -> dict:
        ...


class LoggingDisplayDriver:
    """Development driver that logs the normalized item instead of using hardware."""

    name = "logging"

    def __init__(self) -> None:
        self.current: DisplayItem | None = None
        self.connected = True
        self.last_error: str | None = None

    def show(self, item: DisplayItem) -> None:
        self.current = item
        log.info(
            "display show symbol=%s display=%s name=%s hold_ms=%d",
            item.symbol,
            item.display_name or "-",
            item.name or "-",
            item.hold_ms,
        )

    def clear(self) -> None:
        self.current = None
        log.info("display clear")

    def status(self) -> dict:
        return {
            "connected": self.connected,
            "driver": self.name,
            "current": self.current.symbol if self.current else None,
            "display_name": self.current.display_name if self.current else None,
            "last_error": self.last_error,
        }


class SerialDisplayError(RuntimeError):
    """Base error for Arduino serial communication failures."""


class SerialDisplayDriver:
    """Driver for the Arduino MAX7219 panel serial protocol."""

    name = "serial"

    def __init__(
        self,
        *,
        port: str | None = None,
        baudrate: int = 115200,
        timeout: float = 0.25,
        write_timeout: float = 1.0,
        reset_wait: float = 2.0,
        ack_timeout: float = 1.0,
        expect_ack: bool = True,
        serial_factory: Callable[..., Any] | None = None,
    ) -> None:
        self.port = port or "auto"
        self.baudrate = int(baudrate)
        self.timeout = float(timeout)
        self.write_timeout = float(write_timeout)
        self.reset_wait = max(0.0, float(reset_wait))
        self.ack_timeout = max(0.05, float(ack_timeout))
        self.expect_ack = expect_ack
        self._serial_factory = serial_factory
        self._serial: Any | None = None
        self.current: DisplayItem | None = None
        self.connected = False
        self.last_error: str | None = None
        self.resolved_port: str | None = None

    def show(self, item: DisplayItem) -> None:
        normalized = normalize_emoji(item.symbol, item.name)
        display_name = item.display_name or normalized.display_name
        hold_ms = max(0, int(item.hold_ms))
        self._send_command(f"EMO {display_name} {hold_ms}")
        self.current = DisplayItem(
            symbol=item.symbol,
            name=item.name,
            hold_ms=hold_ms,
            display_name=display_name,
            display_symbol=item.display_symbol or normalized.display_symbol,
        )

    def clear(self) -> None:
        self._send_command("CLEAR")
        self.current = None

    def status(self) -> dict:
        if not self.connected:
            self._ensure_open(raise_on_error=False)
        return {
            "connected": self.connected,
            "driver": self.name,
            "current": self.current.symbol if self.current else None,
            "display_name": self.current.display_name if self.current else None,
            "display_symbol": self.current.display_symbol if self.current else None,
            "last_error": self.last_error,
            "port": self.resolved_port or self.port,
            "baudrate": self.baudrate,
        }

    def close(self) -> None:
        if self._serial is None:
            return
        try:
            self._serial.close()
        finally:
            self._serial = None
            self.connected = False

    def _send_command(self, command: str) -> None:
        ser = self._ensure_open(raise_on_error=True)
        assert ser is not None

        try:
            ser.write((command + "\n").encode("ascii"))
            ser.flush()
            if self.expect_ack:
                self._read_ack(command)
        except Exception as exc:
            self.last_error = str(exc)
            self.connected = False
            try:
                ser.close()
            except Exception:  # noqa: BLE001 - best-effort close on broken ports
                pass
            self._serial = None
            if isinstance(exc, SerialDisplayError):
                raise
            raise SerialDisplayError(str(exc)) from exc

        self.last_error = None

    def _ensure_open(self, *, raise_on_error: bool) -> Any | None:
        if self._serial is not None and getattr(self._serial, "is_open", True):
            self.connected = True
            return self._serial

        try:
            factory = self._serial_factory or _pyserial_factory()
            resolved_port = (
                auto_detect_serial_port(
                    serial_factory=factory,
                    baudrate=self.baudrate,
                    timeout=self.timeout,
                    write_timeout=self.write_timeout,
                    reset_wait=self.reset_wait,
                    ack_timeout=self.ack_timeout,
                )
                if self.port == "auto"
                else self.port
            )
            if not resolved_port:
                raise SerialDisplayError("serial port is not configured")
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

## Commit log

2026-05-17 Implement Arduino serial emoji display service
2026-05-18 Improve Arduino emoji display behavior and normalization
2026-05-18 Log resolved Arduino port on startup
    [driver.py]
2026-05-31 Tune Arduino panel startup and brightness
2026-05-31 Add enclosure files and hardware docs
    [Bottom.stl, Display.stl, Glass.stl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]
